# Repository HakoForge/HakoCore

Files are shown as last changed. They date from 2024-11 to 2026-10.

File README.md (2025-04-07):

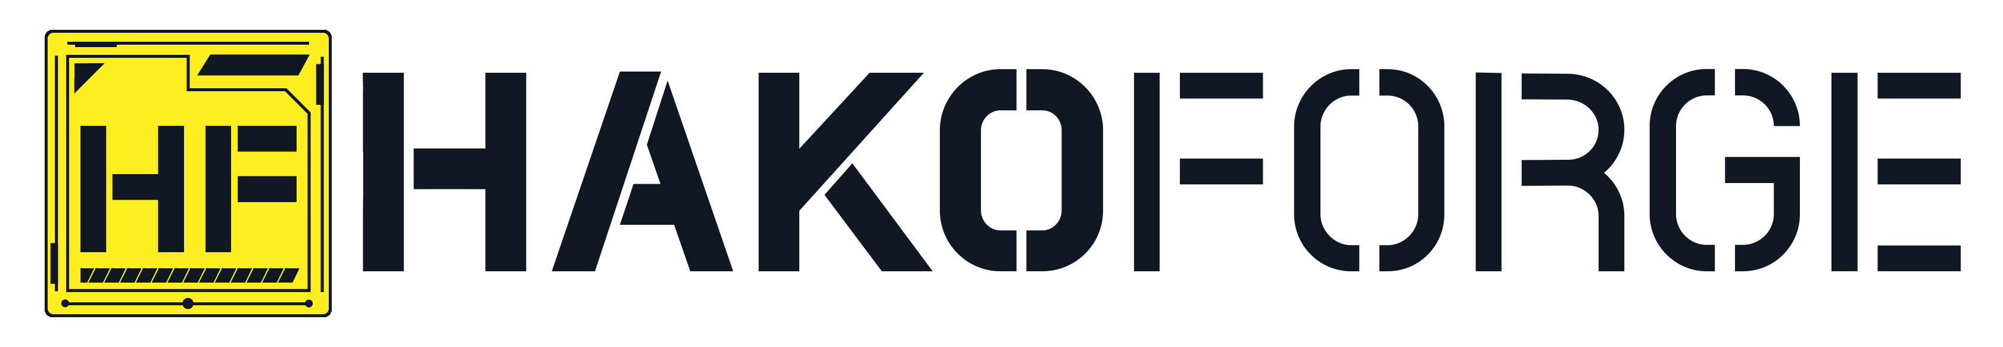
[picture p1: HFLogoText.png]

# WELCOME TO THE FORGE!
HakoForge will share 3D models and documentation on our [GitHub](https://github.com/HakoForge/HakoCore). Our hope for this project is to have the community's ideas contribute to the development of the products. Join our Discord to see what others are doing with their HakoCore and let us know what you would like to see.<br/>
[HakoForge](https://hakoforge.com/)<br/>
[Reddit](https://www.reddit.com/r/hakoforge/)<br/>
[Discord](https://discord.com/invite/3kjpbmckgm)<br/>
[Instagram](https://www.instagram.com/hakoforge/)<br/>
[Twitter/X](https://x.com/HakoForge)<br/>
# HakoCore User Manual
[Latest Version (V1.0)](https://raw.githubusercontent.com/HakoForge/HakoCore/refs/heads/main/HakoCore%20User%20Manual%20V1.0.pdf)
  - HakoCore User Manual and PCB spec sheets
  
The HakoCore will be continually evolving and documentation may be changed or updated. Visit our [GitHub](https://github.com/HakoForge/HakoCore) to see view past versions.

# Cages and PCBs
There are two form factors for the HakoCore system:<br/>

Standard form factor<br/>
Small form factor<br/>

These form factors will be consistent throughout our product line up. This will allow us to develop future products that will be compatible with your HakoCore in the future. We have many in the pipeline, but want to hear from the community on what they would like to see made. 

If you have a knack for 3D modeling, you can use our models as a base and create something unique for your own use. Our PCBs will be available for individual purchase.

We'll added step and procedure for contributing soon.

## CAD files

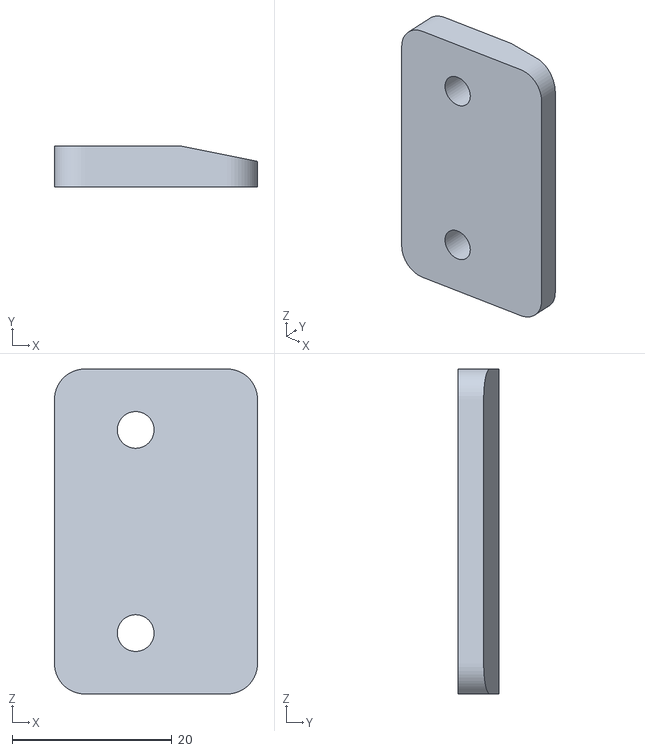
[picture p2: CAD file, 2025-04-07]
Accessories/Case Subparts/PSU Stand.stl
25.4 x 5.08 x 40.6

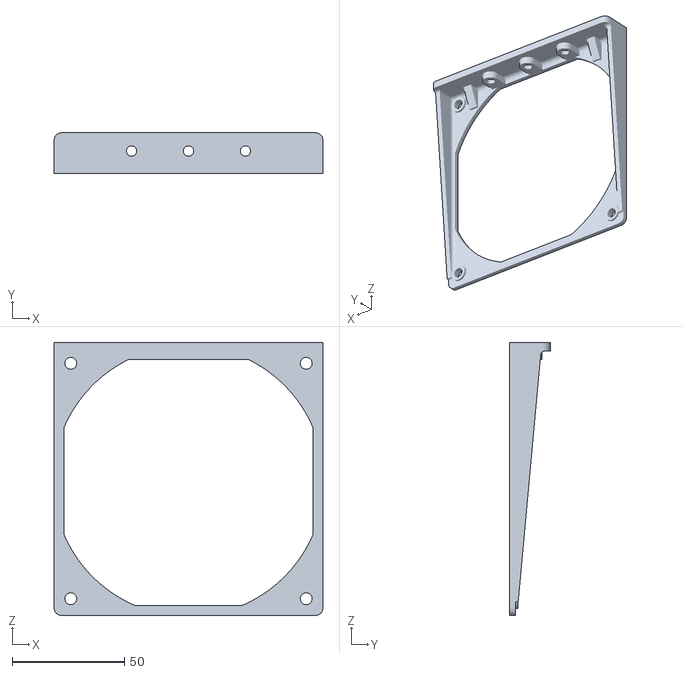
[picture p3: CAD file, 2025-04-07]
Accessories/Fan Mounts/Fan_Bracket_120_90_v2.stl
120.0 x 18.1 x 121.8

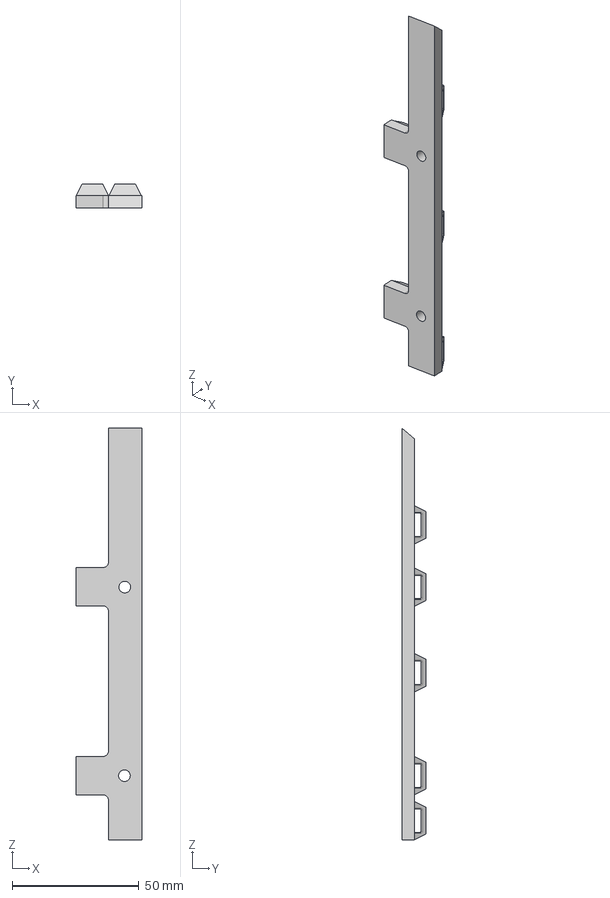
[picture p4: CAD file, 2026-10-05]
Accessories/Other/Cable_Management_A.step
25.9 x 9.65 x 162.7 mm

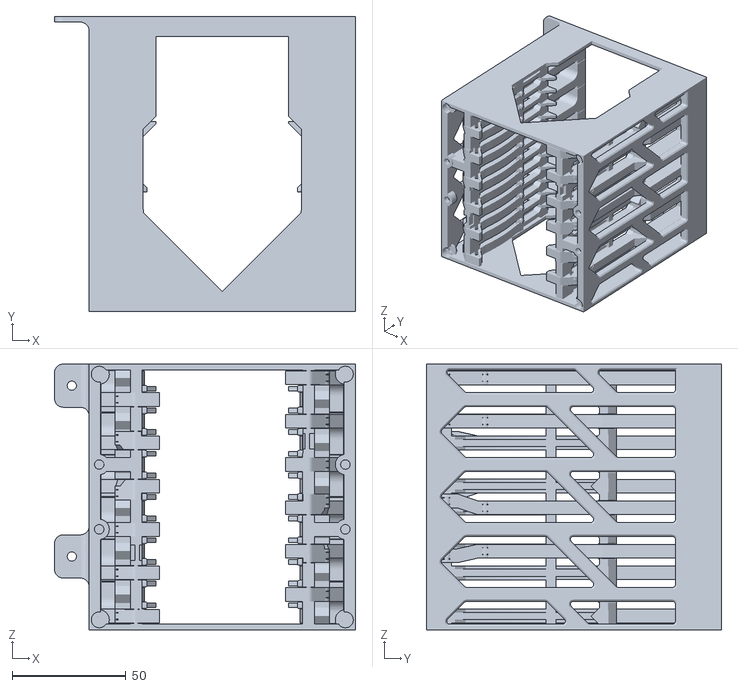
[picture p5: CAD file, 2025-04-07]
Cages/12 SSD Standard Cage/SSD Cage 12 rev1.stl
132.6 x 130.1 x 117.1

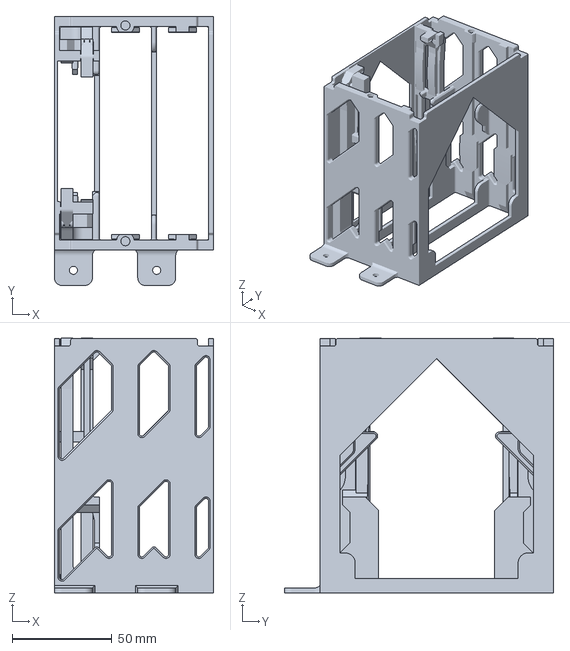
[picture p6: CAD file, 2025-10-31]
Cages/2x2 HDD-SSD Small Cage/Cage 2x2 rev2-1_a.3mf
79.9 x 135.1 x 128.0 mm

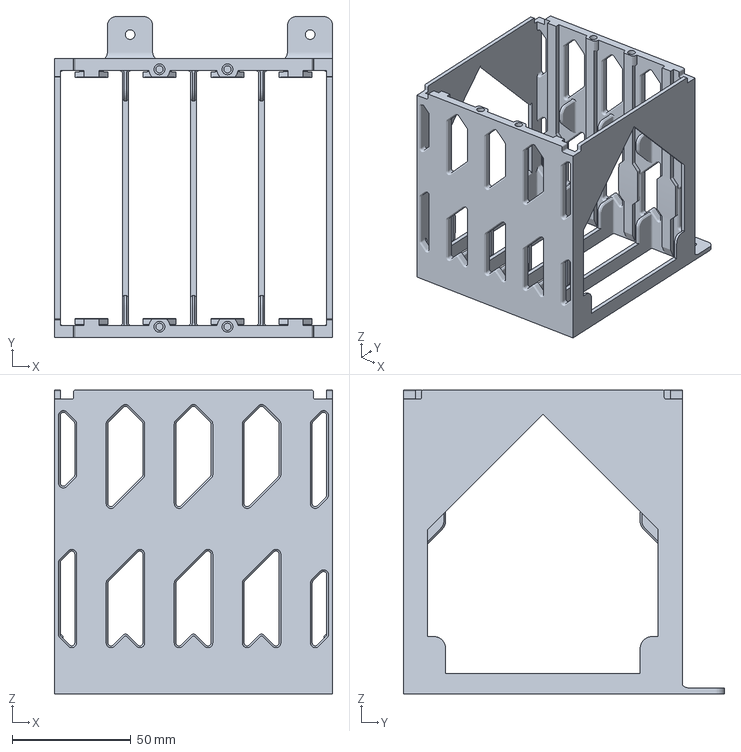
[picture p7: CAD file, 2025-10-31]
Cages/4 HDD Standard Cage/HDD Cage 4 rev2-1_noSupport.3mf
117.1 x 135.1 x 127.9 mm

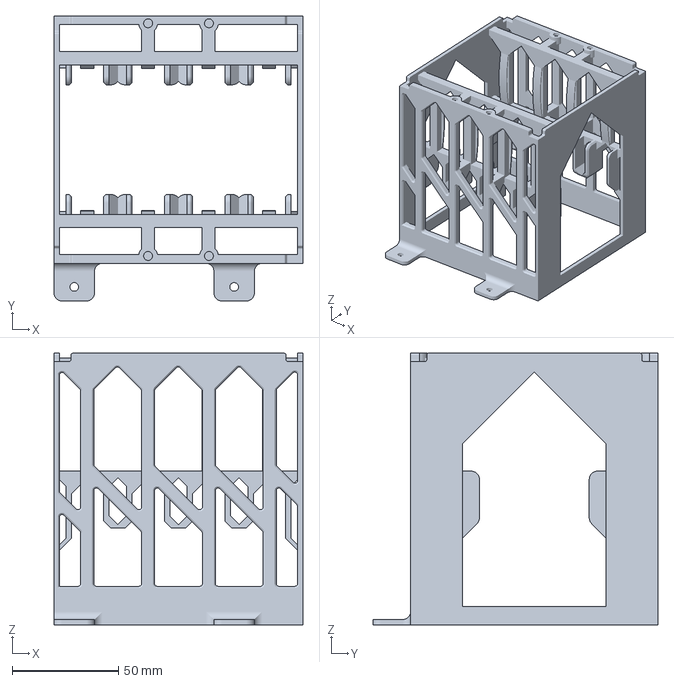
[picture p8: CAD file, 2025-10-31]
Cages/6 U.2 Standard Cage/u.2 15mm Cage rev2-1.3mf
117.1 x 134.1 x 127.9 mm

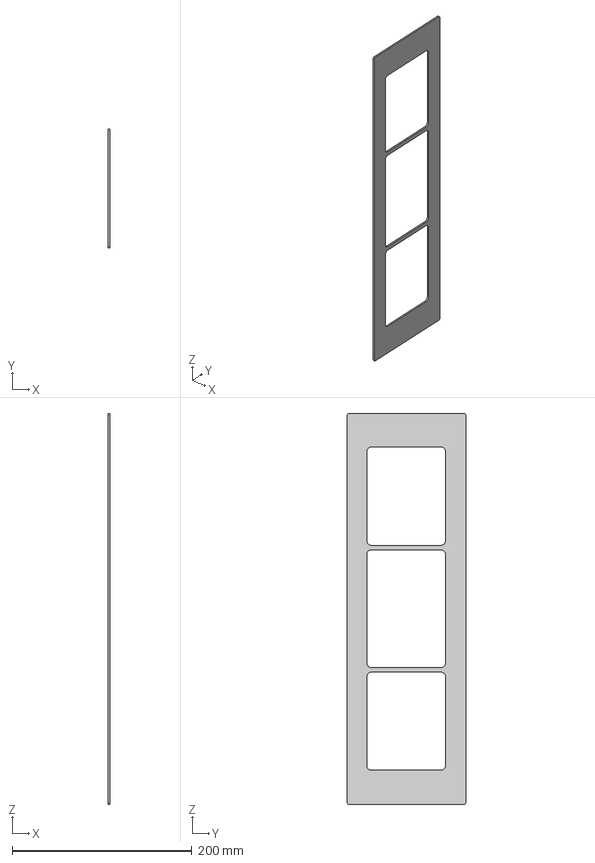
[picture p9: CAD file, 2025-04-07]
Case/Core Mini/Front_Panel_Af.step
2.03 x 132.2 x 435.6 mm

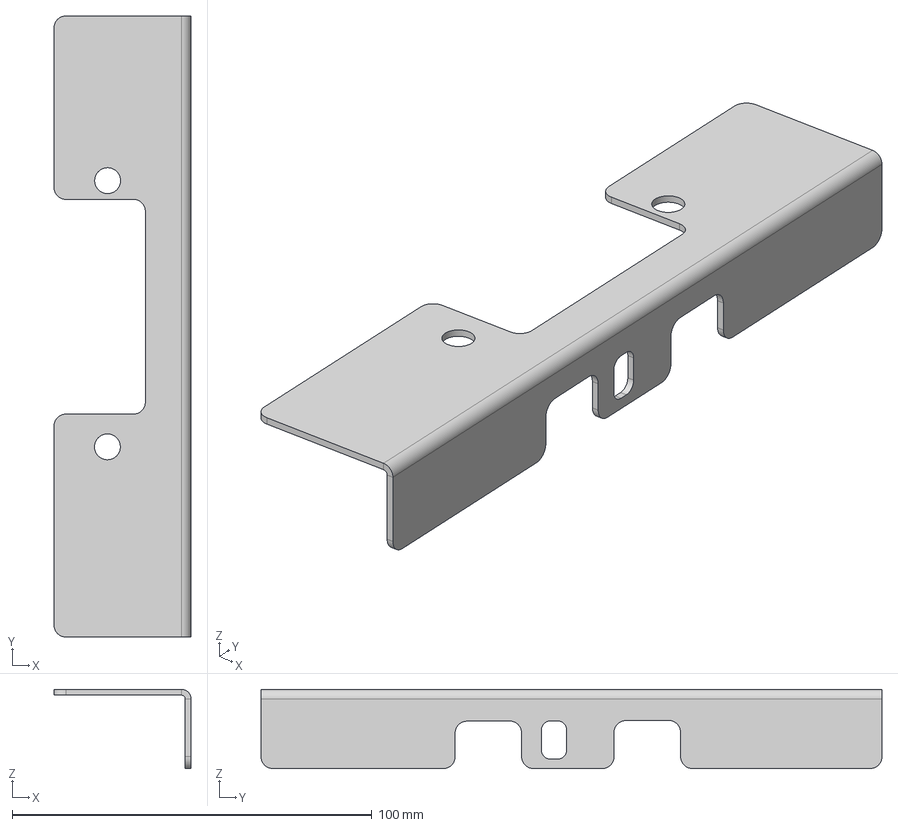
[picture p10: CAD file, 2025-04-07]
Case/Core/Rack_Ears_R.step
38.1 x 172.7 x 22.0 mm

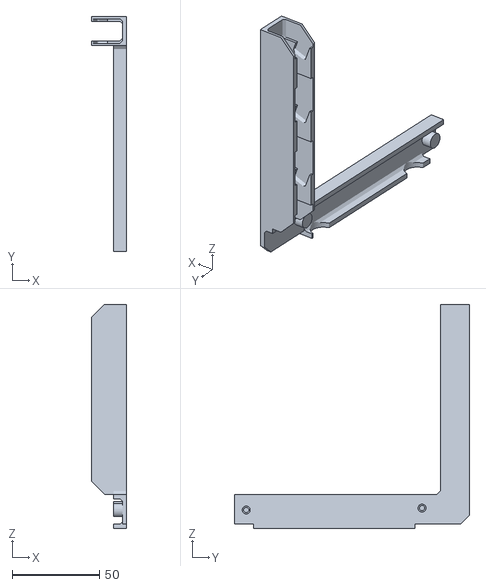
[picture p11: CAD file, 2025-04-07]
Accessories/Case Subparts/AirBlock Ends Right + fans v2.stl
20.3 x 135.0 x 128.8

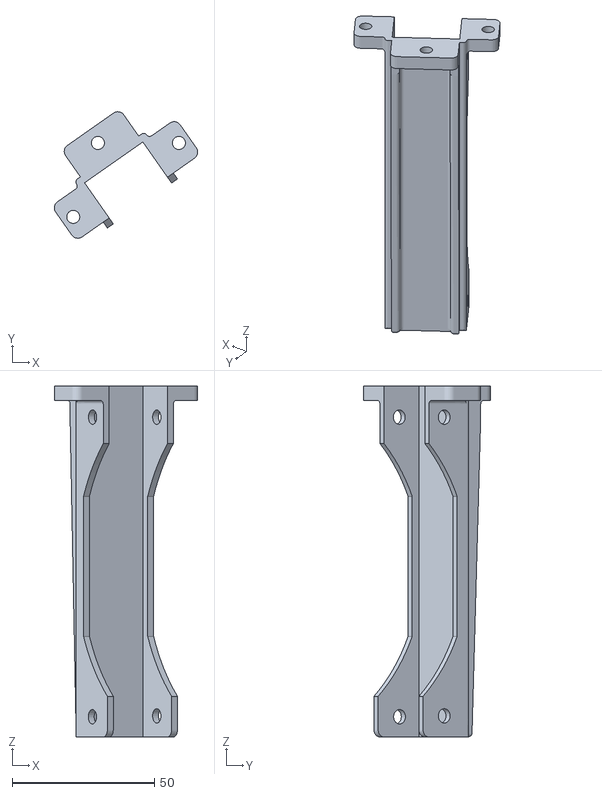
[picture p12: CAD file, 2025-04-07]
Accessories/Fan Mounts/Fan_Bracket_120_55.stl
50.4 x 44.5 x 123.4

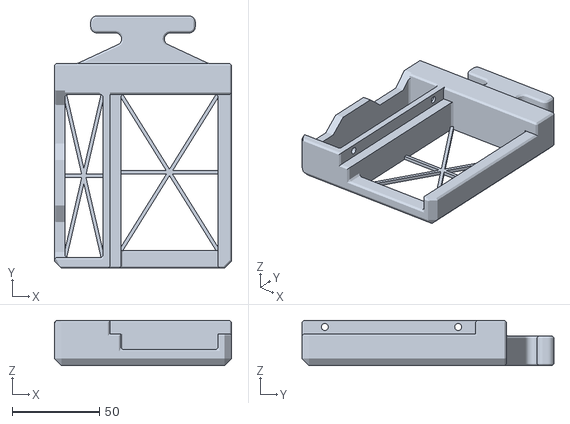
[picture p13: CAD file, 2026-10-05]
Accessories/Other/2.5 7mm SSD Adapter v0.3.stl
101.6 x 144.6 x 26.0

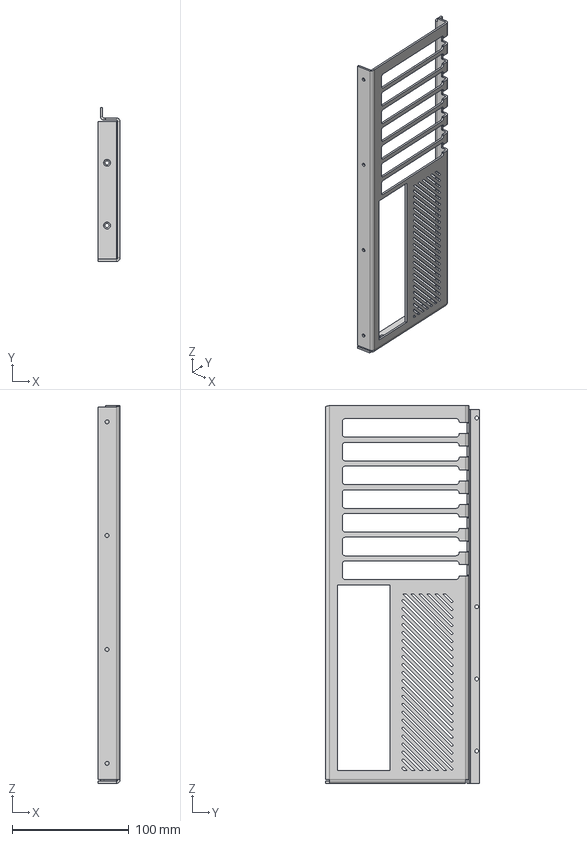
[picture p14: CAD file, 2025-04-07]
Case/Core Mini/PCIe_Bracket.step
19.0 x 132.1 x 323.9 mm

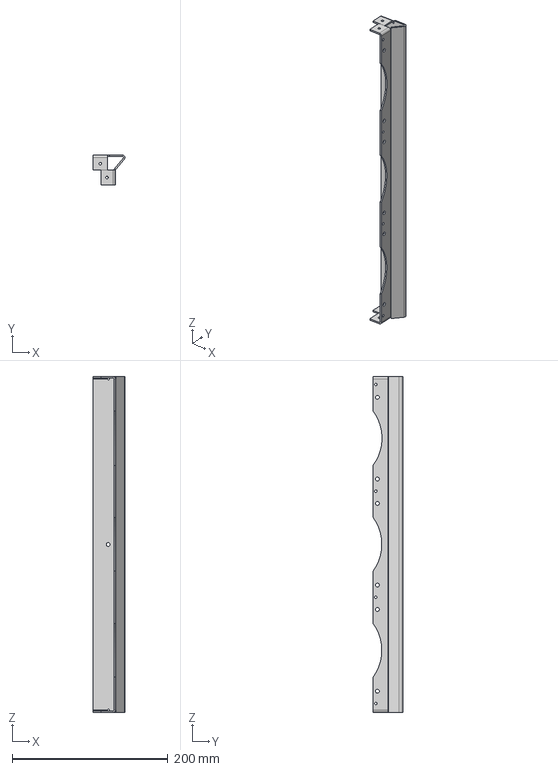
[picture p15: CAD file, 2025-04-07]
Case/Core/Front_Bracket_Tp.step
41.1 x 38.5 x 431.5 mm

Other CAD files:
Cages/2x2 HDD-SSD Small Cage/Cage 2x2 rev2-1_b.3mf
Cages/4 HDD Standard Cage/HDD Cage 4 rev2_a.step
Accessories/Case Subparts/AirBlock Ends Left.stl
Accessories/Fan Mounts/Fan_Bracket_Spacer_55_5.stl
Accessories/Fan Mounts/Fan Mount PCIe.stl
Accessories/Fan Mounts/Fan_Bracket_120_90.stl
Accessories/Fan Mounts/Fan_Bracket_120_PCIe.stl
Accessories/Fan Mounts/Fan_Bracket_120_PCIe_Mirrored.stl
Accessories/Fan Mounts/Fan_Bracket_80_55.stl
Accessories/Fan Mounts/Fan_Bracket_92_55.stl
Accessories/Fan Mounts/Fan_Bracket_Spacer_55_10.stl
Accessories/Fan Mounts/Fan_Bracket_Spacer_90_10_v2.stl
Accessories/Fan Mounts/Fan_Bracket_Spacer_90_5_v2.stl
Accessories/Other/2.5 15mm SSD Adapter v0.3.stl
Accessories/Other/Cable_Management_B.step
Accessories/Other/PCie_Card_Support v1.4.stl
Accessories/Other/PCie_Card_Support v1.4_feet.stl
Accessories/Other/SSD Removal Tool v2.4.stl
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

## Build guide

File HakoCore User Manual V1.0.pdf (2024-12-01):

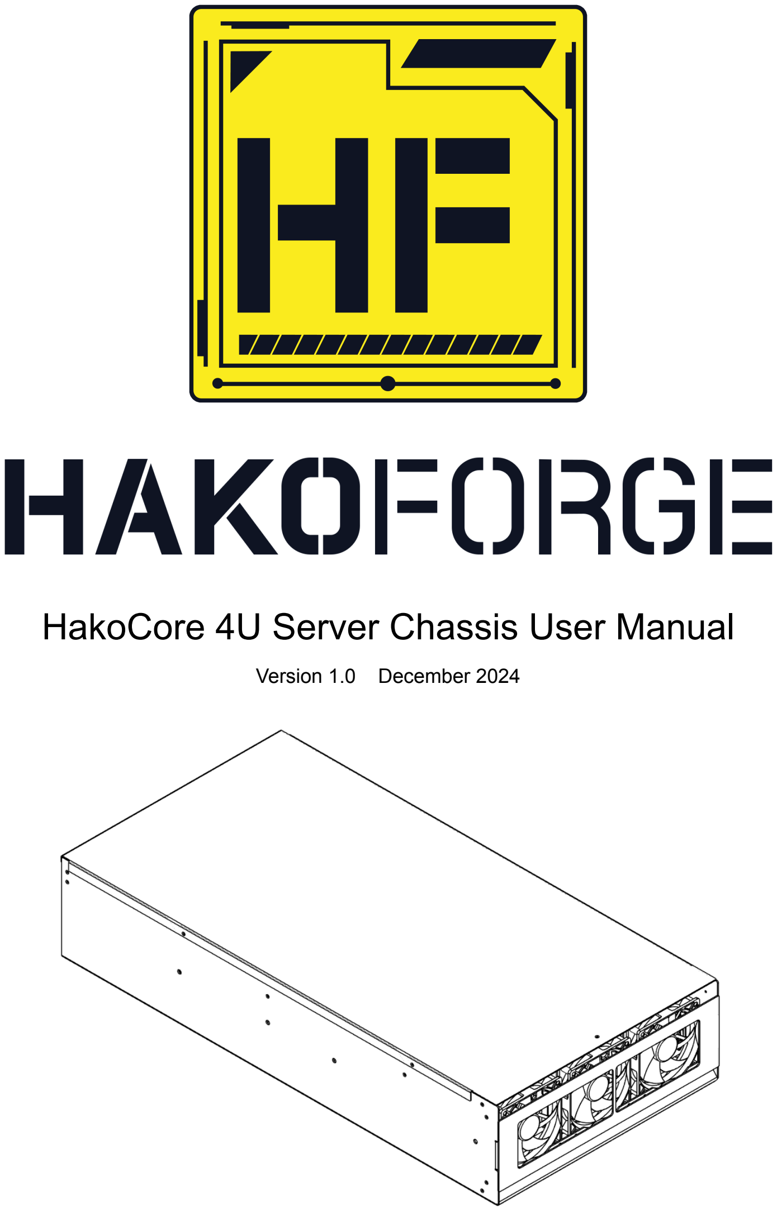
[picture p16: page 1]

## HakoCore 4U Server Chassis User Manual

Version 1.0 December 2024

## HakoCore 4U Server Chassis User Manual

## TABLE OF CONTENTS

WELCOME TO THE FORGE!---------------------------- 2 CAUTIONS---------------------------------------------------- 2 DIMENSIONS AND SPECIFICATIONS---------------- 3 EXPLODED VIEW------------------------------------------- 4 PANEL REMOVAL-------------------------------------------5 POWERBOARD----------------------------------------------6 POWER HARNESS----------------------------------------- 7 WIRE ROUTING----------------------------------------------8 FAN INSTALLATION----------------------------------------9 PCB INSTALLATION--------------------------------------11 CAGE INSTALLATION----------------------------------- 12 WARRANTY------------------------------------------------- 13 Standard 12-SSD Backplane-------------------------- 14 Standard 4-HDD Backplane----------------------------15 Mixed 4-Bay Backplane--------------------------------- 16

## User Manual

## WELCOME TO THE FORGE!

Thank you for supporting HakoForge! Please read this user manual carefully before use. It will explain the installation and usage of the HakoCore chassis components and products. If the HakoCore was purchased as a kit, it will come pre-assembled and ready for use. The HakoCore will be an ongoing project. As new cages or PCBs are made, this manual may be updated or changed. All versions and other documentation can be referenced on our GitHub. For any questions and support, contact us at help@hakoforge.com

## CAUTIONS

The HakoCore includes a powerboard that will be connected to an ATX power supply. Refer to page 5 to understand its usage.

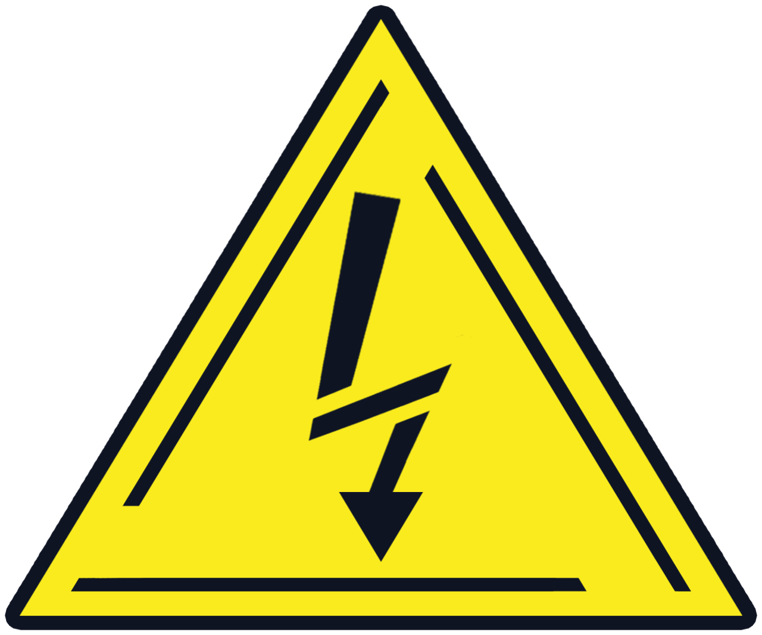
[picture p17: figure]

To protect yourself and other electronic components

- Keep unused connectors clear from contacting other surfaces
- Ensure the proper PSU connectors are used (referring to quick start guide)

## User Manual

## DIMENSIONS AND SPECIFICATIONS

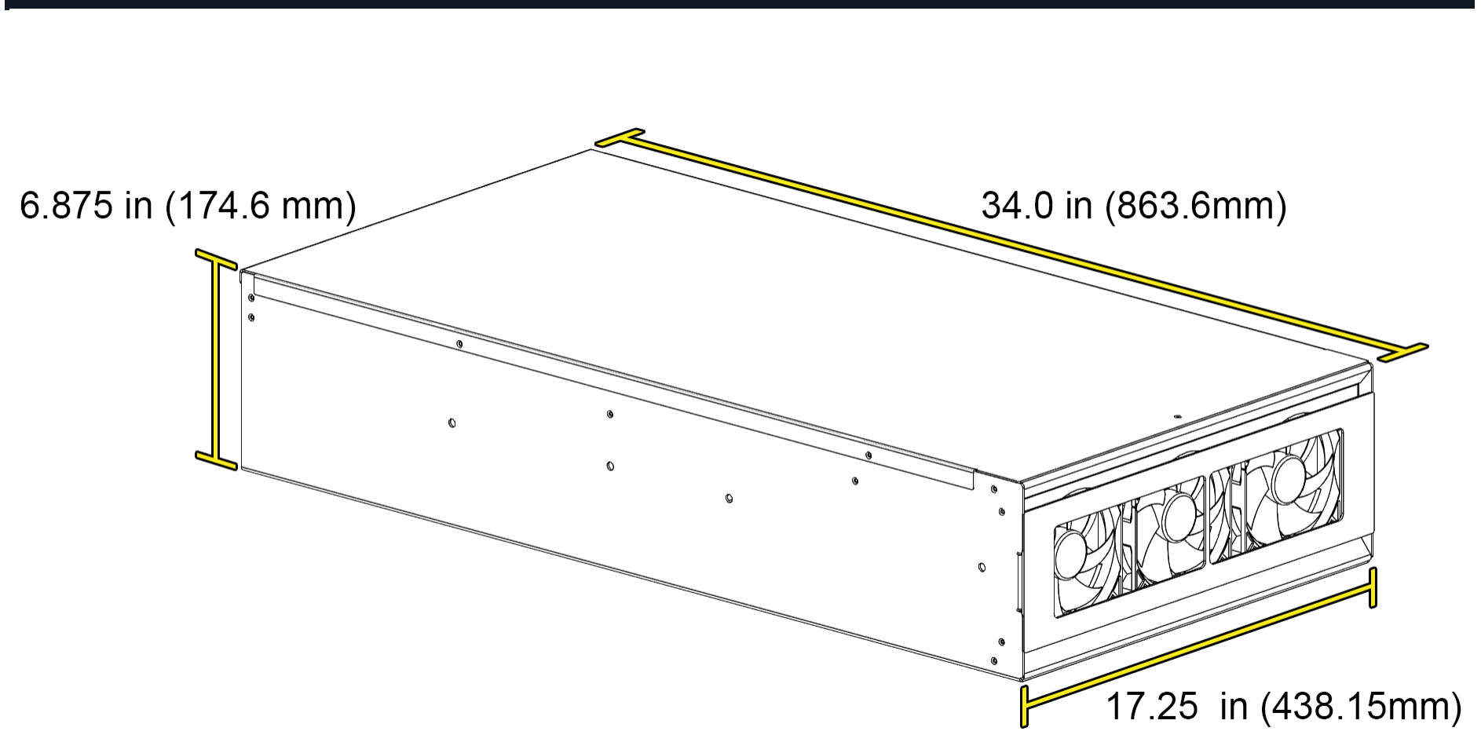
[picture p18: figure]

Weight

With 3 fans, 3 Cages & PCBs, no drives: 20 lbs

With 3 fans, 9 Cages & PCBs, no drives: 25 lbs

With 3 fans, 9 Cages & PCBS, 42 HDD, 6 SSD: ~35lbs to ~90 lbs depending on drives used

Materials | Powder Coated Aluminum
Dimensions | 34" x 17.25" x 6.875"
Drive Power Capability | 1 Powerboard: 600 Watts 2 Powerboards: 1200 Watts
Motherboard Support | Mini-ITX, Micro ATX, ATX, EATX
PSU Support | ATX up to 200mm in length
Fans | 3 included fans with up to 6 additional fans

## User Manual

## EXPLODED VIEW

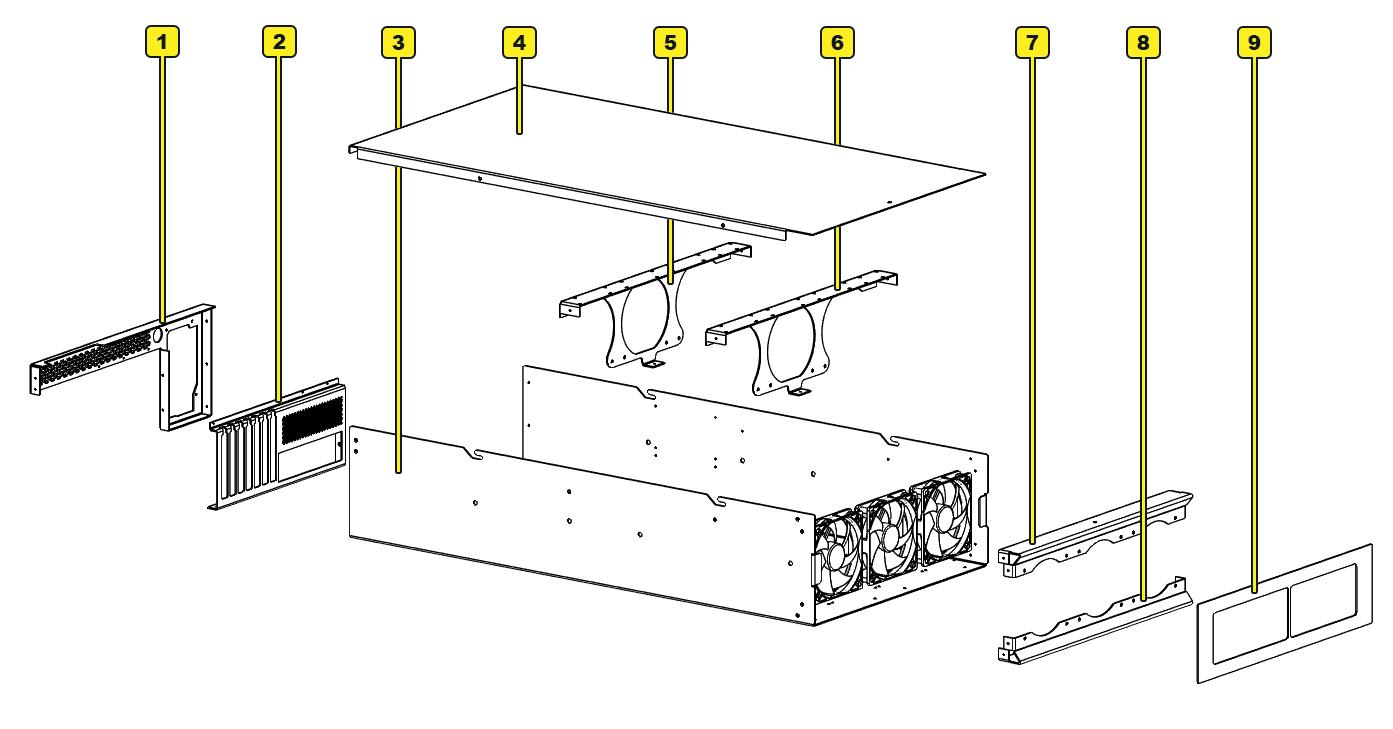
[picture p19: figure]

1 PSU Bracket

2 PCIE I/O Bracket

3 Chassis Body

4 Chassis Lid

5 Rear Cage Bracket

6 Middle Cage Bracket

7 Top Front Fan Bracket

8 Bottom Front Fan Bracket

9 Front Panel

## User Manual

## PANEL REMOVAL

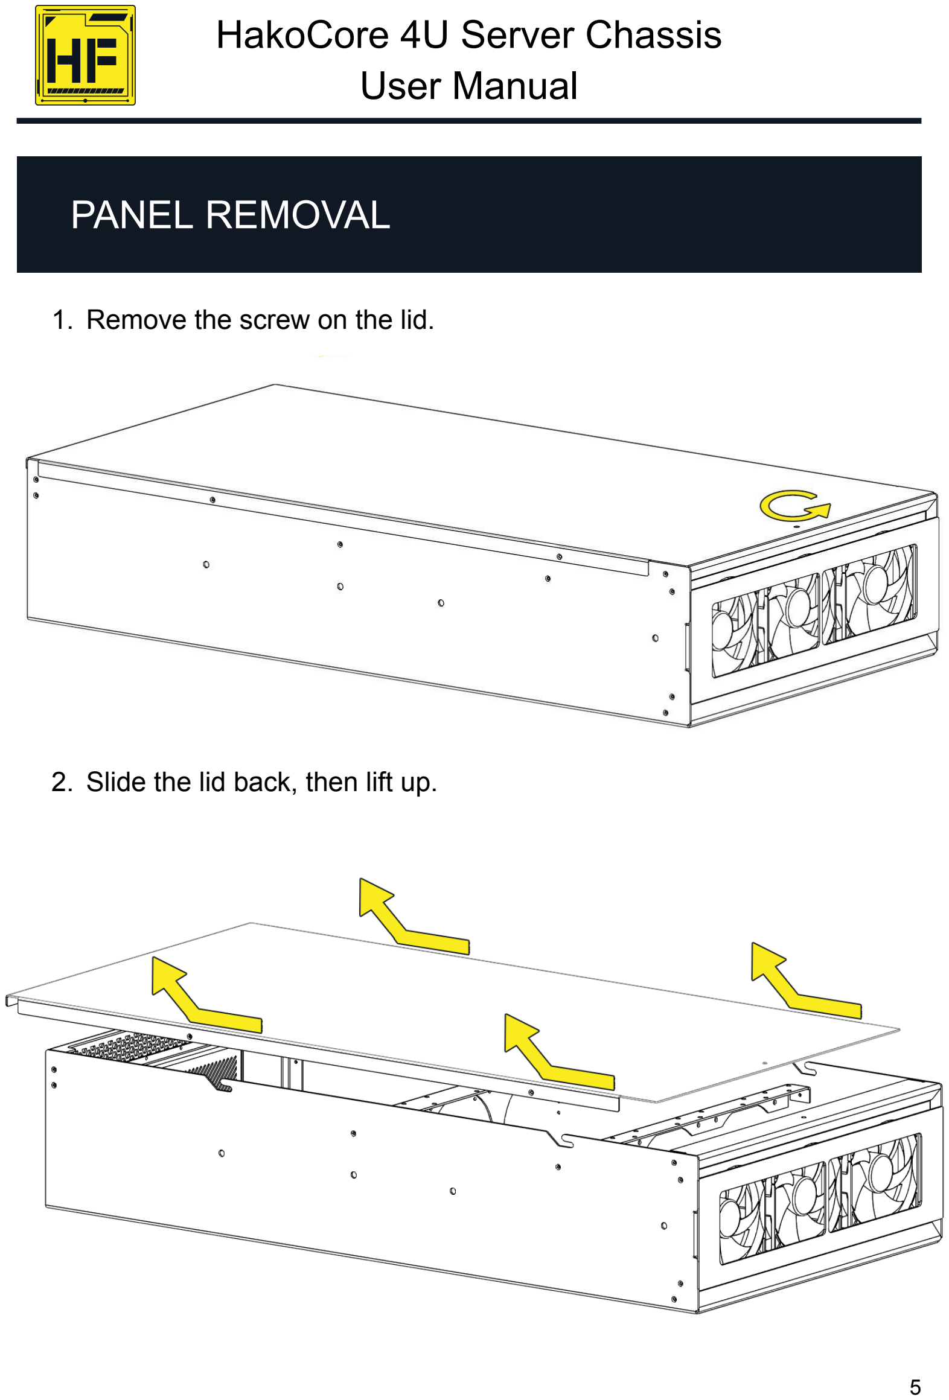
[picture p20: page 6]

1. Remove the screw on the lid.
2. Slide the lid back, then lift up.

## User Manual

## POWERBOARD

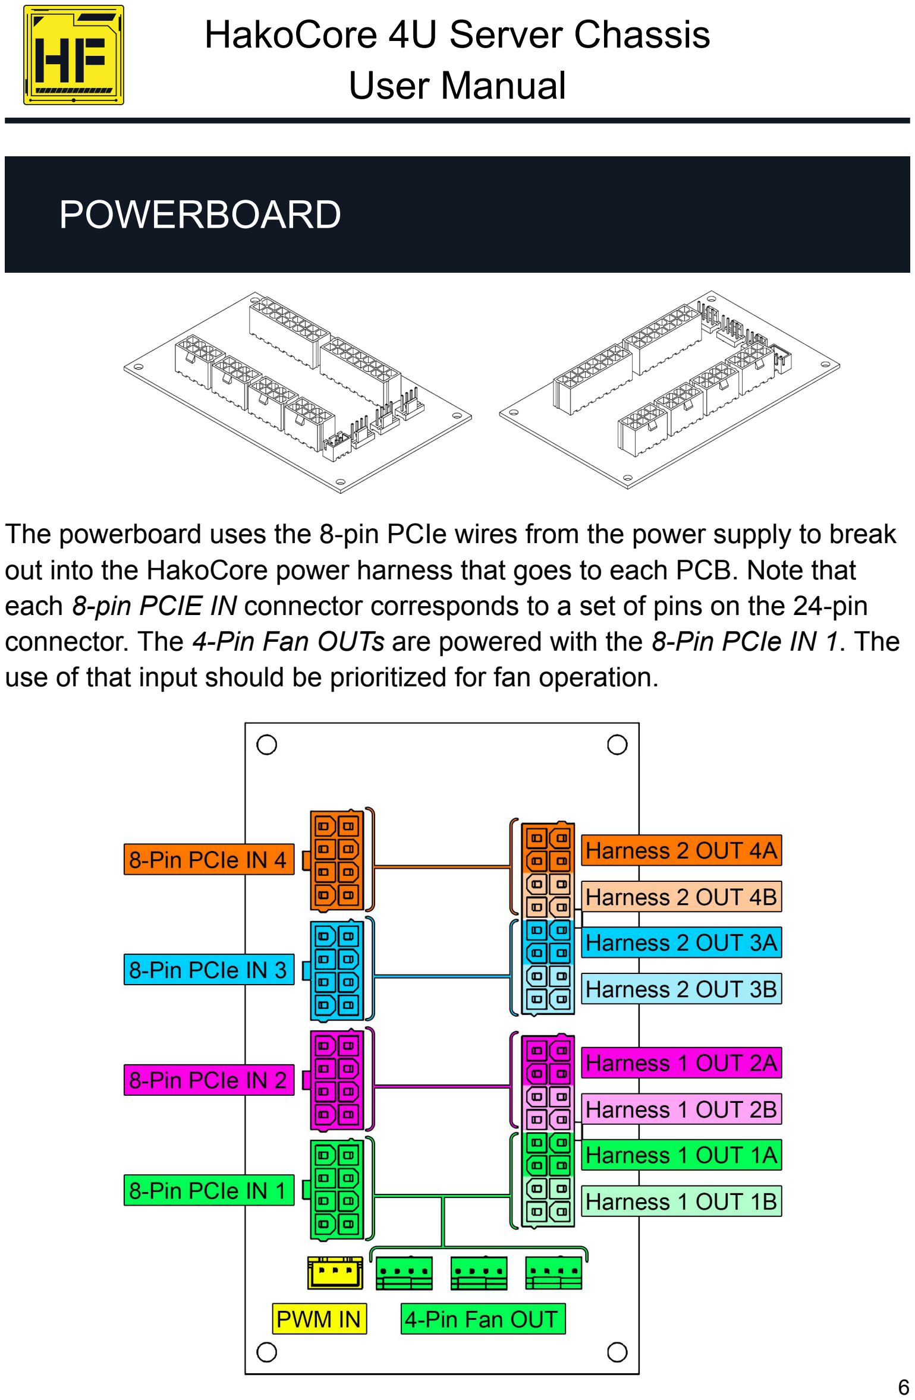
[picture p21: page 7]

The powerboard uses the 8-pin PCIe wires from the power supply to break out into the HakoCore power harness that goes to each PCB. Note that each 8-pin PCIE IN connector corresponds to a set of pins on the 24-pin connector. The 4-Pin Fan OUTs are powered with the 8-Pin PCIe IN 1. The use of that input should be prioritized for fan operation.

## User Manual

## POWER HARNESS

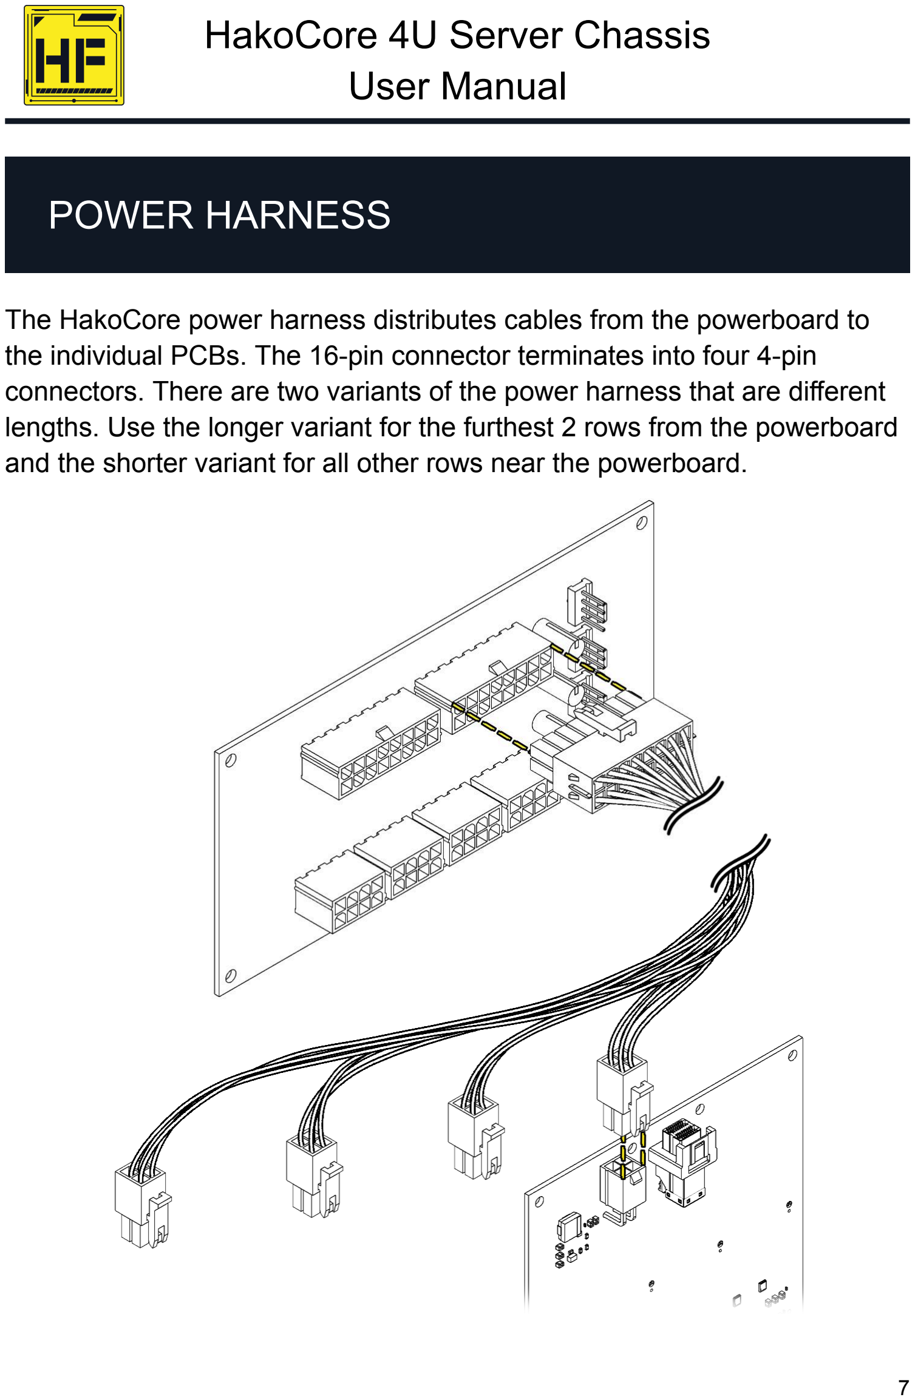
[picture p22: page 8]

The HakoCore power harness distributes cables from the powerboard to the individual PCBs. The 16-pin connector terminates into four 4-pin connectors. There are two variants of the power harness that are different lengths. Use the longer variant for the furthest 2 rows from the powerboard and the shorter variant for all other rows near the powerboard.

## User Manual

## WIRE ROUTING

The HakoCore, when purchased with the PCB kits, will come pre-assembled and cable managed. There will be zip-tie locations along the standoffs of the PCBs. When managing cables yourself, we recommend the following practices.

- Route longer cables along the outer edge of the case. This will take up more slack and reduce any tangling that may occur.
- Route the HakoCore power harness towards the powerboard side of the case.
- Route SAS cables away from the powerboard side of the case, or straight across the PCBs.
- Use the zip-tie locations to secure cables and avoid collision with the PCB connectors.

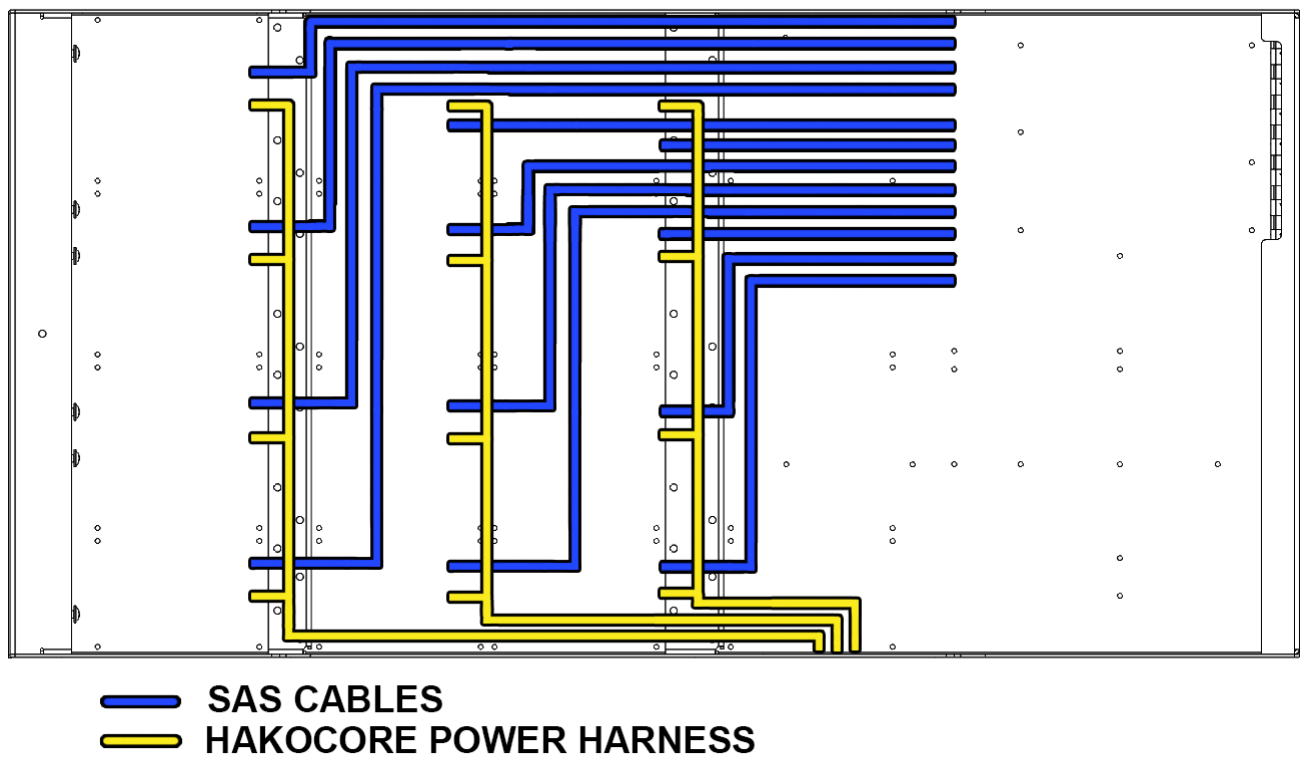
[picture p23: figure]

## User Manual

## FAN INSTALLATION

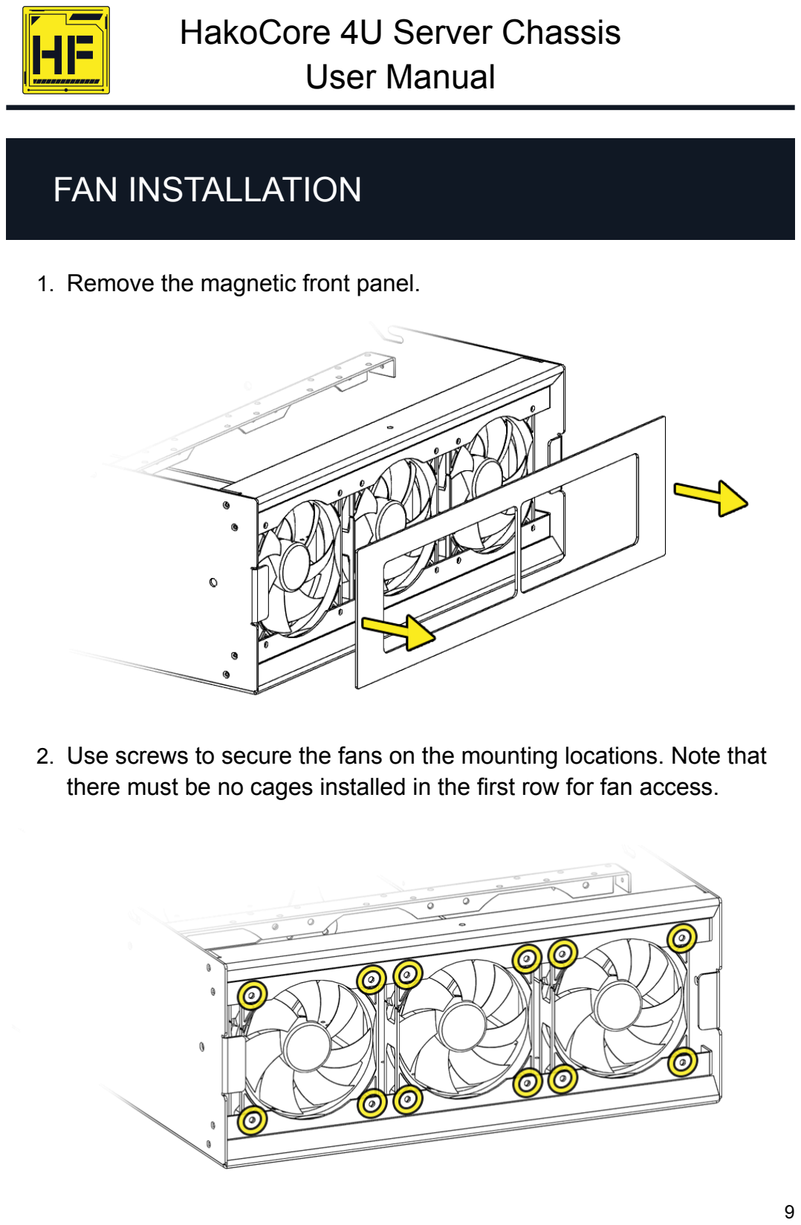
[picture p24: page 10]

1. Remove the magnetic front panel.
2. Use screws to secure the fans on the mounting locations. Note that there must be no cages installed in the first row for fan access.

## User Manual

## FAN INSTALLATION (CONTINUED)

3. The rear cage bracket and middle cage bracket has mounting locations for up to 6 additional fans. Note that there must be no cages around the respective rows for fan access.

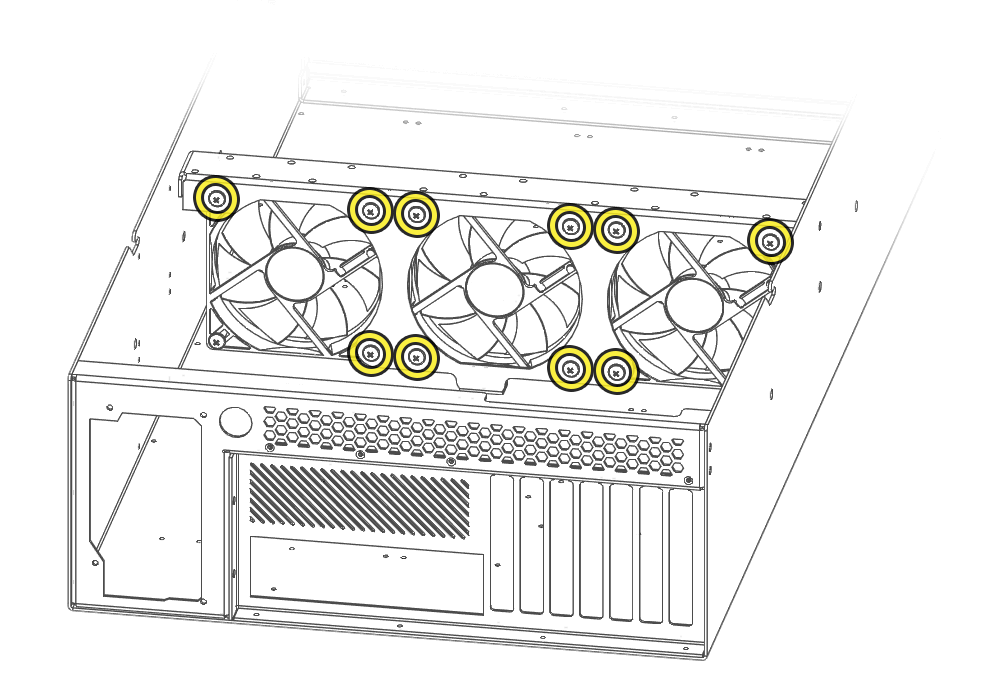
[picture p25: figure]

## User Manual

## PCB INSTALLATION

1. Use screws to mount the corners of the PCB on the respective stand offs

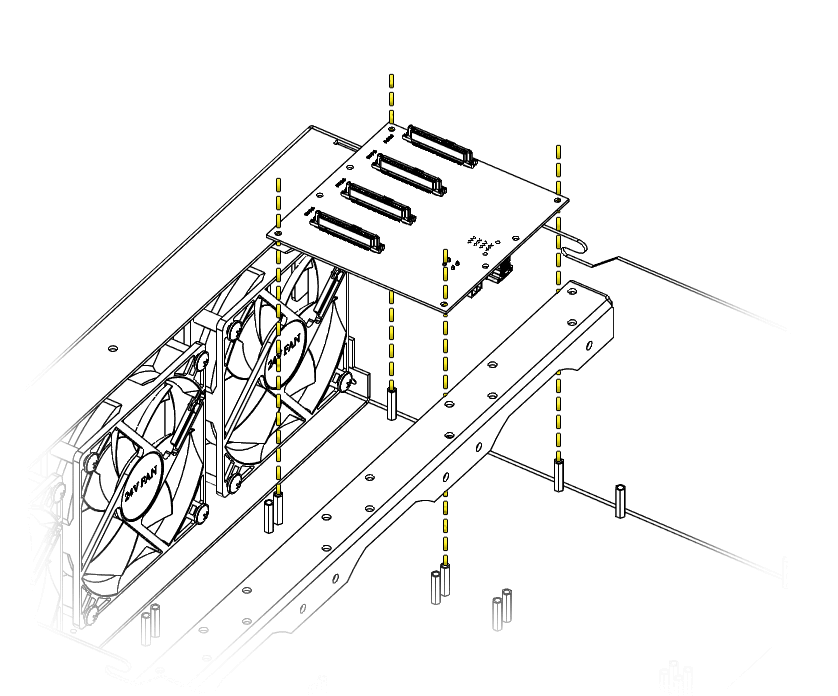
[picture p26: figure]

## User Manual

## CAGE INSTALLATION

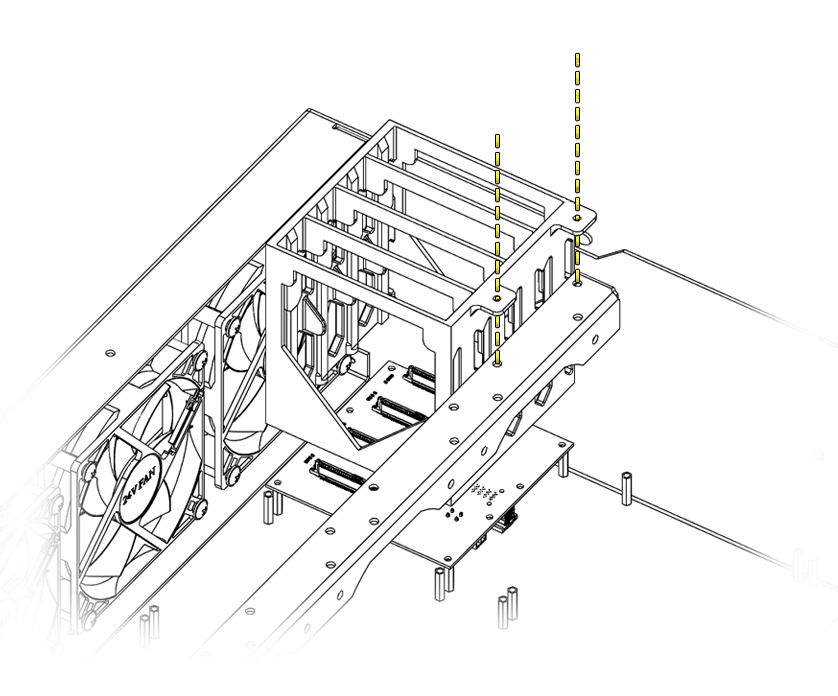
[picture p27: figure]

1. Use thumb screws to secure the cage tabs onto the cage bracket.

## User Manual

## WARRANTY

All HakoForge products come with a 90-day limited warranty. Contact us at help@hakoforge.com for warranty support.

This warranty is limited to the original purchaser and warrants that the product is free from manufacturing defects for the specified time period.

This warranty does not cover damage or problems caused by, but not limited to:
- Wear and tear from normal use
- Any improper use that does not follow procedures described in the manual
- Any accidents or modifications
- Incorrect use with a power supply

HakoForge recommends regular backups and proper data storage practices. HakoForge is not responsible for any data loss that may occur.

## User Manual

Standard 12-SSD Backplane

Specifications

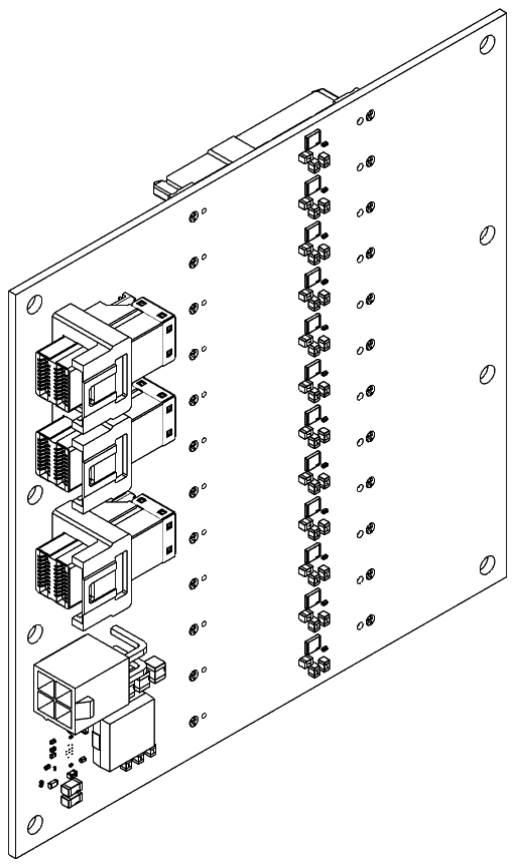
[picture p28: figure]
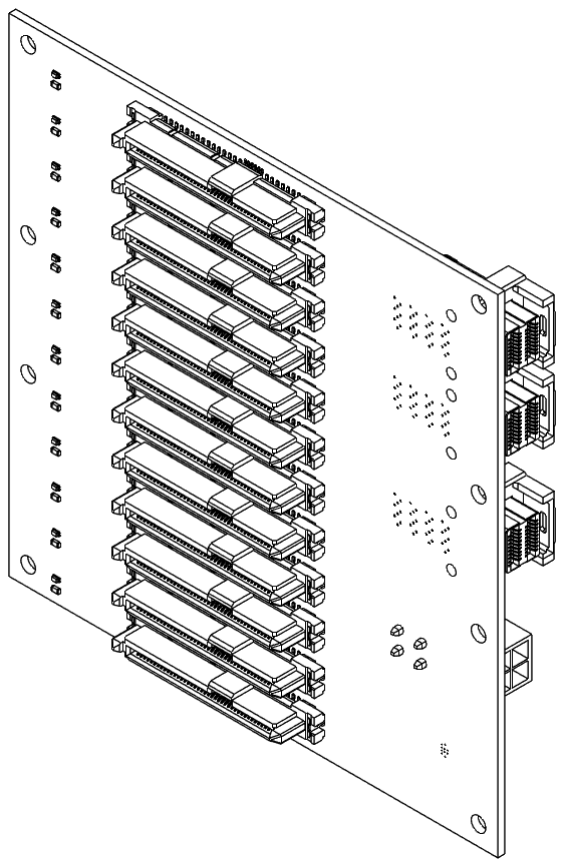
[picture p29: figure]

Connectivity | 12 SATA/SAS 2.5” Drive Connectors 3 SAS Out Connectors
Input | 12V
Output | 5V (25A Max)
Max Power Consumption | 84 Watts

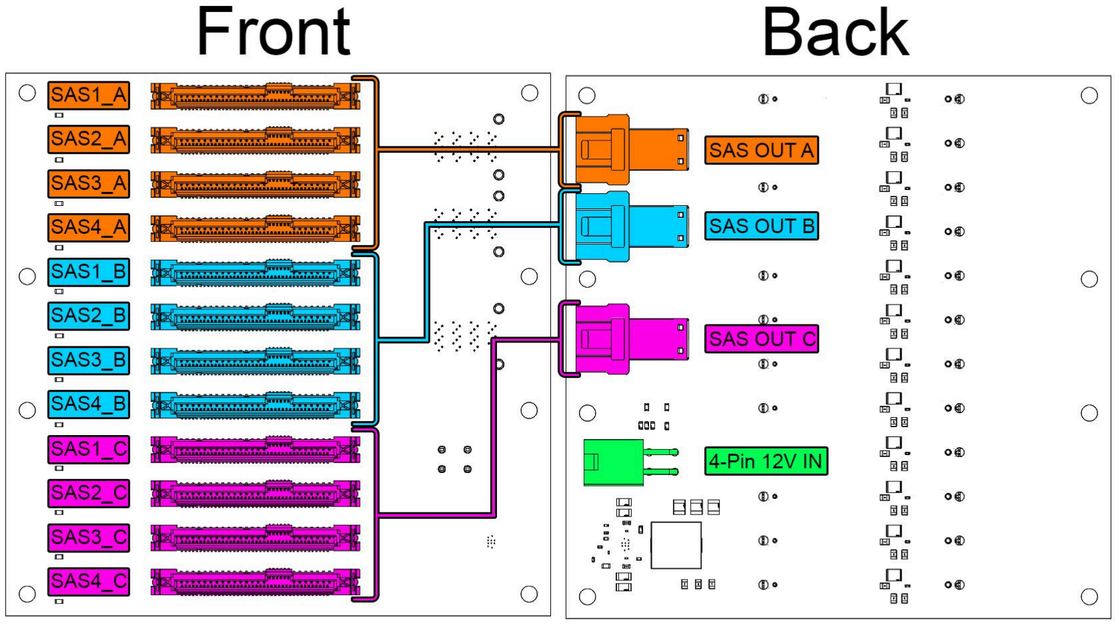
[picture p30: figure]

## User Manual

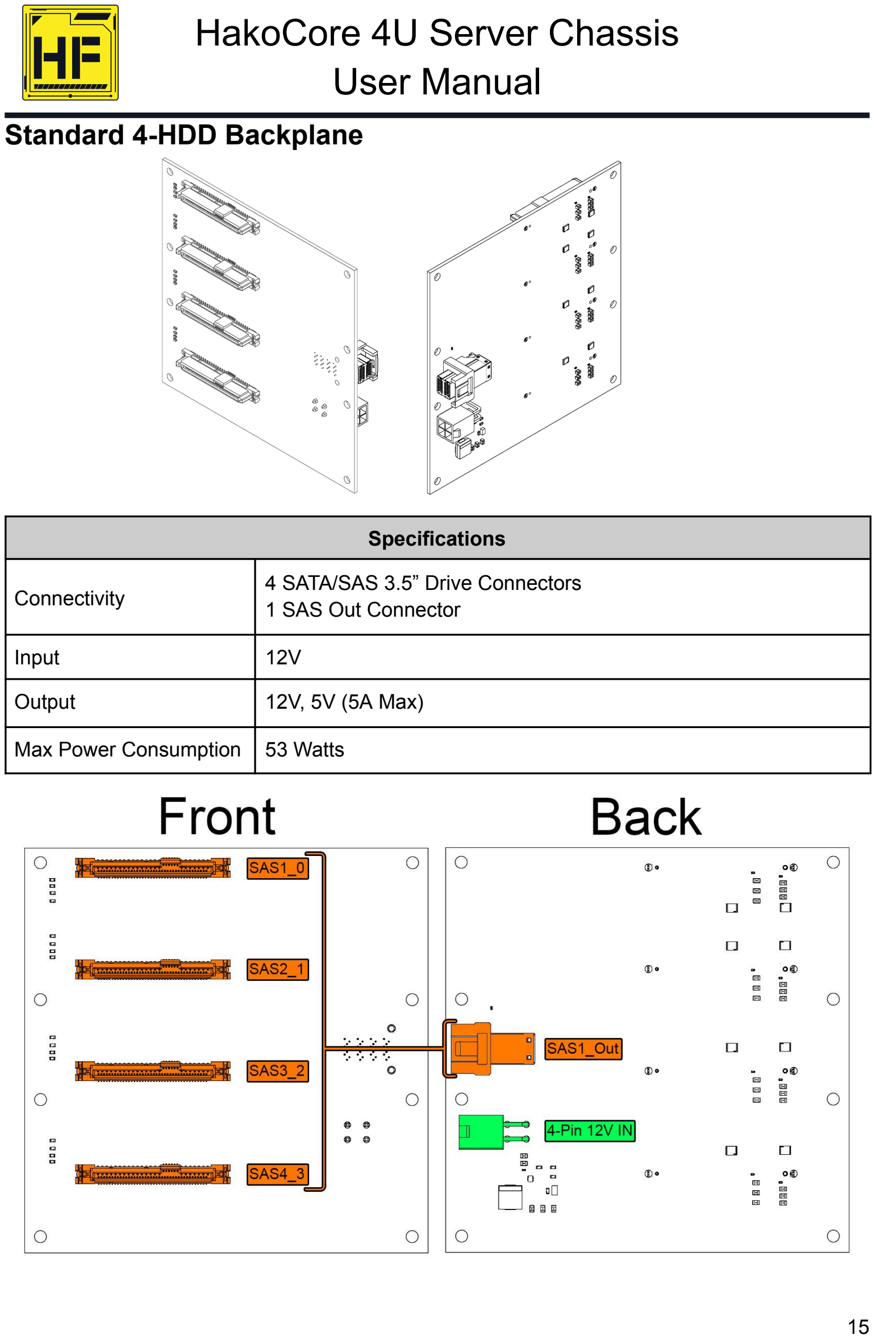
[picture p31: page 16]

Standard 4-HDD Backplane

Specifications

Connectivity | 4 SATA/SAS 3.5” Drive Connectors 1 SAS Out Connector
Input | 12V
Output | 12V, 5V (5A Max)
Max Power Consumption | 53 Watts

## User Manual

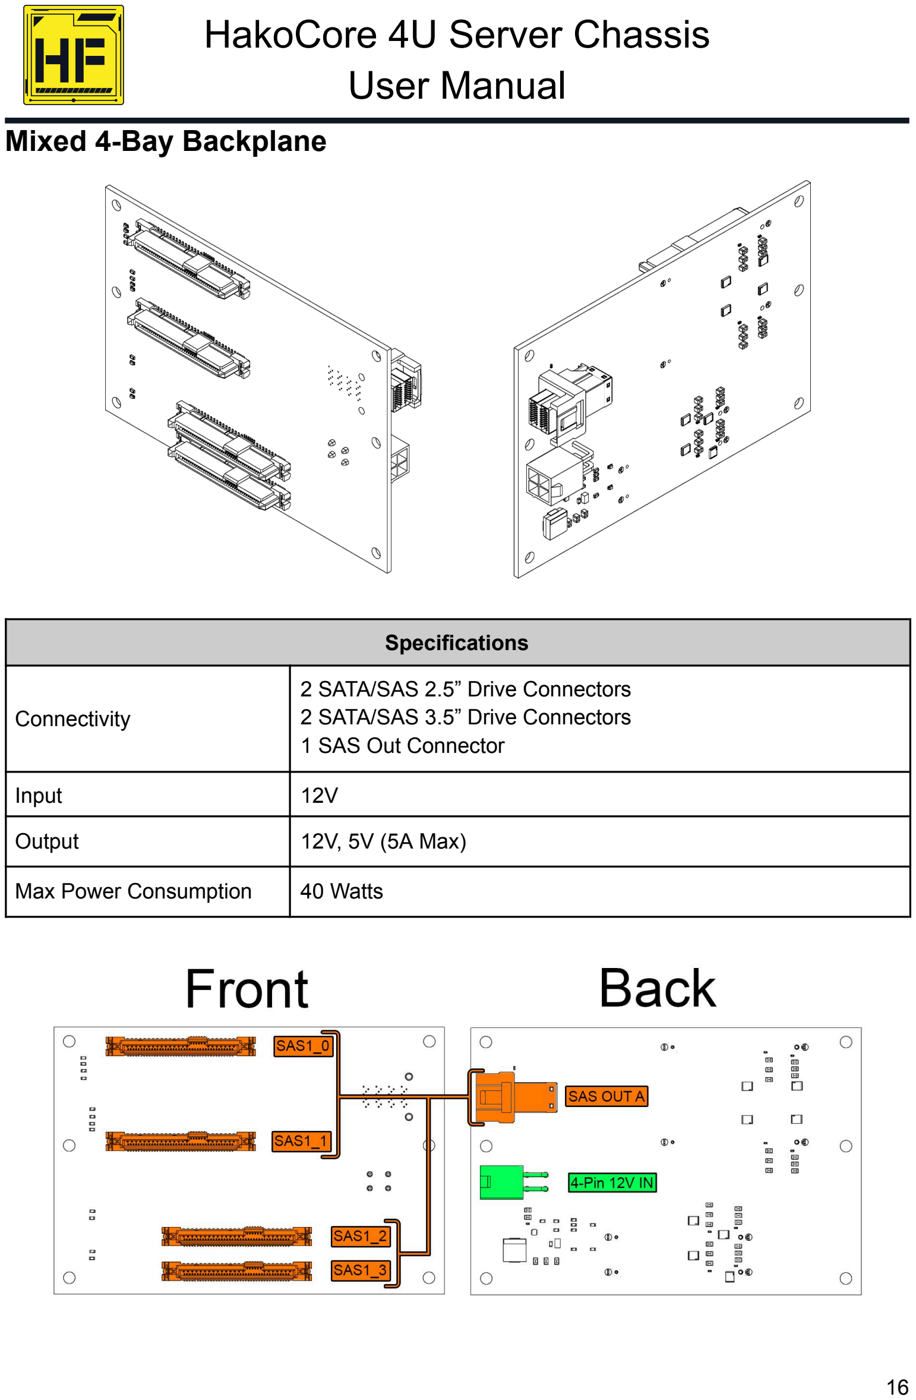
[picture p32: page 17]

Mixed 4-Bay Backplane

Specifications

Connectivity | 2 SATA/SAS 2.5” Drive Connectors 2 SATA/SAS 3.5” Drive Connectors 1 SAS Out Connector
Input | 12V
Output | 12V, 5V (5A Max)
Max Power Consumption | 40 Watts

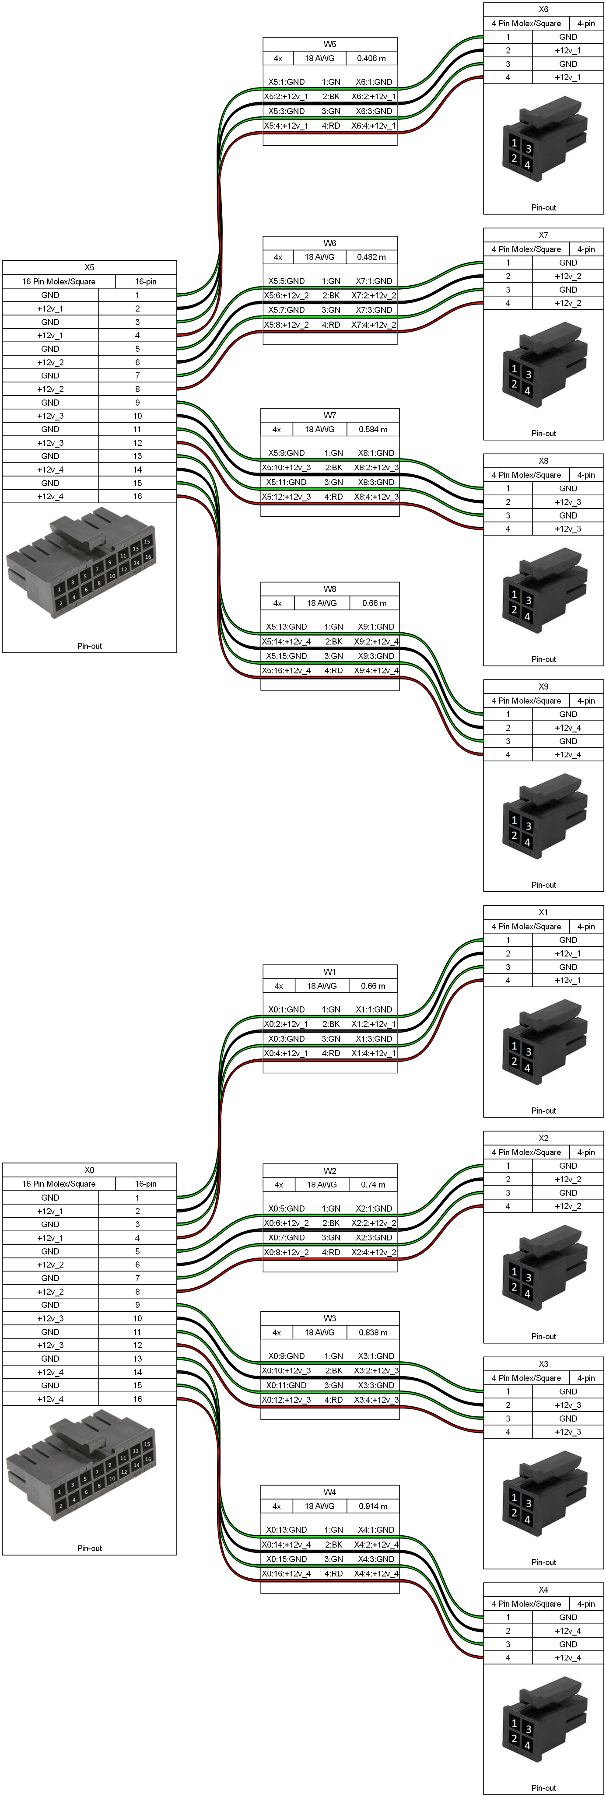
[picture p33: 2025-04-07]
Accessories/Wiring/power.png

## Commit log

2024-12-28 Updated Folder Structure & Added stls
    [Drive Cage mini_3v4_L.3mf, Drive Cage mini_3v4_L.stl, Drive Cage mini_3v4_R.3mf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]
2025-04-07 Updated Folder Structure and removed all out of date items. Rev1 Release
    [Hako_Feet.3mf]
2025-04-16 Added & Updated 4HDD cage model a&b
    [HDD Cage 4 rev2_a.stl, HDD Cage 4 rev2_a.step]
2025-10-31 Archived older files and added latest version of rev2-1 u.2,HDD cages.
    [Cage 2x2 rev1.step, Cage 2x2 rev1.stl, Cage 2x2 rev1_b.step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]
2026-10-05 Added STL for additional accessories + fixed typo
    [2.5 15mm SSD Adapter v0.3.stl, 2.5 7mm SSD Adapter v0.3.stl, Cable_Management_A.step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]
